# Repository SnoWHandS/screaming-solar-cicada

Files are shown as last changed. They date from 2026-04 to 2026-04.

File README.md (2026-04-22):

# Screaming Solar Cicada

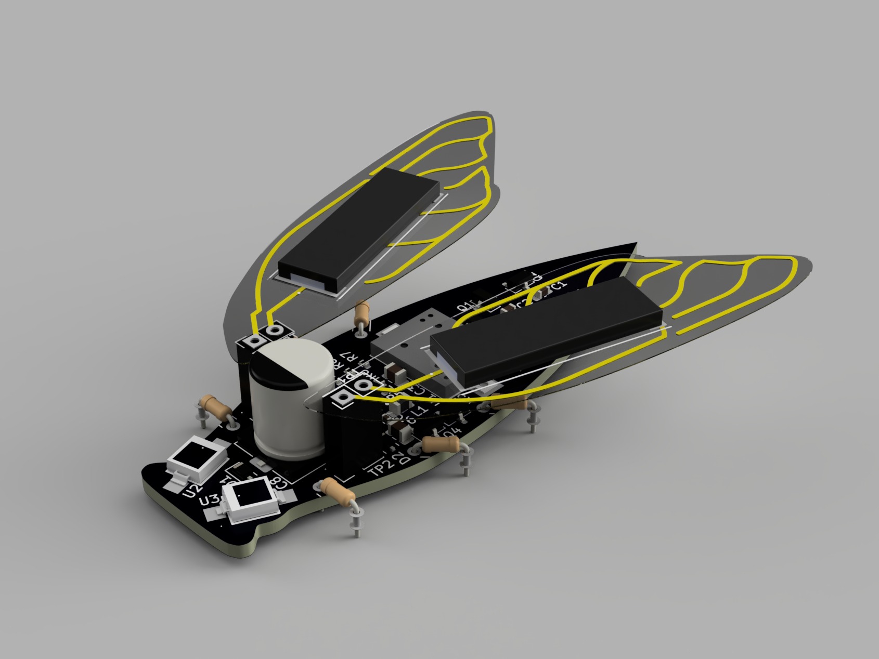
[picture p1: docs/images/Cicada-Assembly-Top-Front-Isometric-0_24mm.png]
Top Front Isometric View

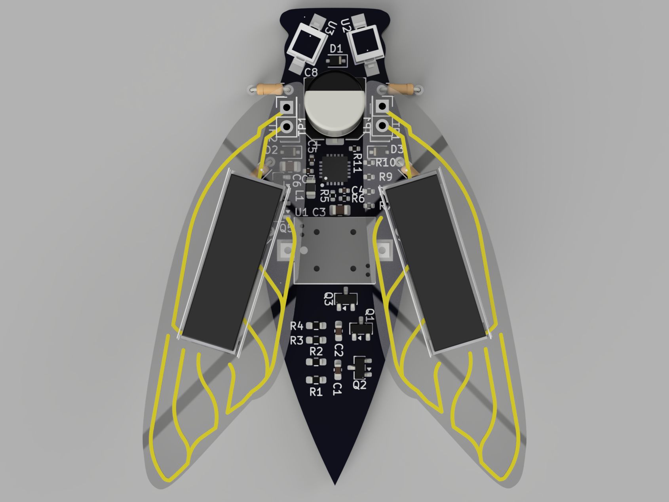
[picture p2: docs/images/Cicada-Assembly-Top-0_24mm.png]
Top View


A sun-fed, MCU-free noise bug that trickle-charges from a tiny **Anysolar KXOB** “SolarBIT” module, then screams in bursts when the storage node crosses a “battery good” threshold—then goes quiet until the cap refills. No code, no sleep states—just **PV → boost → cap → hysteresis → load switch → discrete astable → magnetic buzzer.**

---

## How it works (signal chain)

### 1. Harvest (KXOB)

The main energy source is a compact monocrystalline **KXOB** module—for example **KXOB25-04X3F** / **-TR** class (~22 × 7 mm, ~2 V MPP neighborhood, ~10–15 mA-scale current under decent light).

- The panel feeds `VIN_DC` through a **BAT54-class Schottky** (polarity, forward drop, and saner behavior when the charger isn’t drawing).
- **Stringing:** This design targets **1S** (one module) so `VIN_DC` stays inside the **BQ25505** window. **2S** only if you prove worst-case open-circuit never violates `VIN_DC` limits (**~5.1 V** recommended, **5.5 V** abs max). **Parallel** modules are fine for more charging current in weak light.

### 2. PMIC

**TI BQ25505** — **22 µH** boost from `VIN_DC` ↔ `LBOOST`; cold-start from **~600 mV** typical at the input (after the diode, plan margin), then normal operation down to very low `VIN` once running.

**MPPT** uses a high-impedance divider on `VOC_SAMP` from `VIN_DC` so the chip tracks a fraction of the panel’s open-circuit voltage (KXOB **V<sub>OC</sub>** is usually **~2–3 V** class depending on SKU and illumination).

### 3. Storage and thresholds

Energy stacks on the storage / `VSTOR`–`VBAT_*` network. The main reservoir is a large electrolytic (**1000 µF / 6.3 V** on the tank in `crktboi`).

| Function | Programming |
|---|---|
| **`VBAT_OV`** | Two-resistor divider from `VRDIV` — build uses **~6.8 MΩ + 6.2 MΩ** (~**13 MΩ** total class). |
| **`VBAT_OK`** | Three-resistor string (**~5.1 MΩ + 5.11 MΩ + 5.11 MΩ** class) — rising vs falling “turn load on/off” vs **`VBIAS` ≈ 1.21 V**. |

Sanity-check **`VBAT_OV` ≥ `VBAT_OK` rising threshold** per TI ordering rules; divider pin mapping matters.

### 4. Load switch

`VBAT_OK` drives **2N7002** → **AO3401A** high-side: **`Vstore` → `+3V0`** to the audio section. When the tank sags past the low trip, `+3V0` collapses and the chirp ends.

### 5. Noise

**BC847** astable — **~174 kΩ** + **1 nF** timing (**~4 kHz** ballpark), **~1 kΩ** collectors. **GSC1102YB-3V4000** buzzer does the actual scream.

#### Oscillator Design

The discrete astable multivibrator is built around a pair of BC847 NPN transistors. The selected RC timing values (`174 kΩ` and `1 nF`) tune the oscillation frequency to approximately 4 kHz, which closely matches the resonant frequency of the magnetic buzzer to produce the loudest possible chirp.

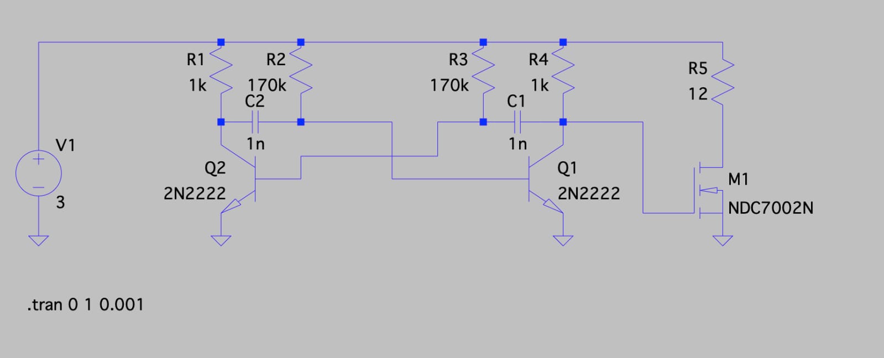
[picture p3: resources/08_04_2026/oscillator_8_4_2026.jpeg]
Astable Multivibrator Schematic


*Schematic of the oscillator circuit.*

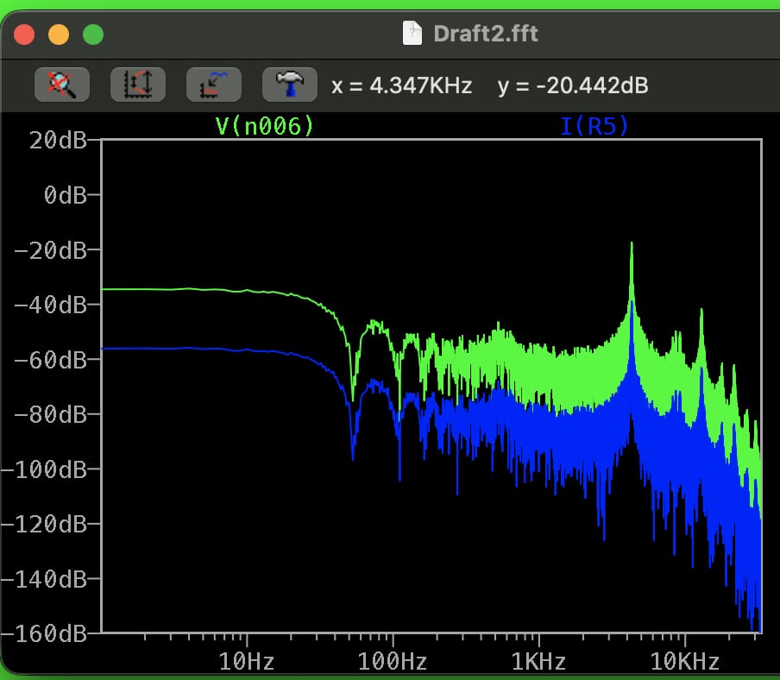
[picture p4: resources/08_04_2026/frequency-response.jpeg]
Oscillator Frequency Response


*Frequency response showing the ~4 kHz operating point.*

---

## Early direction (not the hero)

The first concept used **arrays of VBPW34S photodiodes** (**3S×3P** strings, per-string Schottkys, picky light economics). That stays interesting as a stunt, but this description treats it as **initial exploration** — the **KXOB** is the practical, repeatable harvester you’d actually leave on a windowsill.

---

## Repo / CAD

**KiCad** project **`crktboi`**:

- **`power`** sheet — KXOB / `VIN_DC`, BQ25505, load switch  
- **`oscillator`** sheet — astable + buzzer  

**ERC** and **Highlight net** are the real documentation.

---

## Expectations

- **Chirp cadence** — charge rate from the KXOB in your real light vs load current when the PFET is on — scale like **Δ*t* ~ *C*·Δ*V* / *I*<sub>load</sub>**.
- **Louder / longer** — more µF or lower mean buzzer current.
- **More frequent chirps** — more mW from the cell or a tighter OK window (trade noise against TI threshold constraints).

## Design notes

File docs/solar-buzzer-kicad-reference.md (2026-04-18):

# Solar buzzer — KiCad implementation reference

Reference diagrams and wiring notes for the solar-diode–powered buzzer: photodiode array, BQ25505, load switch, and astable oscillator. Example values reference `jmny-crkt` and **`crktboi/power.kicad_sch`** as implemented.

**Same-sheet net labels:** In KiCad, **local (or global) labels** connect nets without drawing every wire across the sheet. **ERC**, **Tools → Update PCB from Schematic**, and **right-click → Highlight net** are authoritative. Simple geometric “tracers” that only follow wires and ignore label names will falsely show pins as unconnected.

**VSTOR vs VRDIV (TI datasheet):** Pin **19 (VSTOR)** is the boost output—“typically connected to the **system load**”—with **CSTOR** (e.g. 4.7 µF + 0.1 µF) to VSS. You do **not** tie the tops of the **VBAT_OV** / **VBAT_OK** resistor strings to VSTOR. Those strings are biased from pin **8 (VRDIV)** (“connect high side of resistor divider networks to this biasing voltage”). **OK_HYST** / **OK_PROG** are midpoints of dividers **between VRDIV and GND**. **VOC_SAMP** (MPPT) is a midpoint of a divider **between VIN_DC and GND** (or other connections per datasheet), not from VRDIV. The chip pulses VRDIV during sampling so divider current is not continuous.

**Wrong advice (do not follow):** “Connect VSTOR to the L1 / input-side tank node; relabel nets.” **Ignore that.** VSTOR is **not** on the inductor or VIN path. The only place `L1` belongs is **between VIN_DC (pin 2) and LBOOST (pin 20)**. The “tank” / bulk storage lives on **VBAT_PRI / VBAT_SEC / mux** per your topology—not wired to the switching node.

---

## 1. Overall block diagram

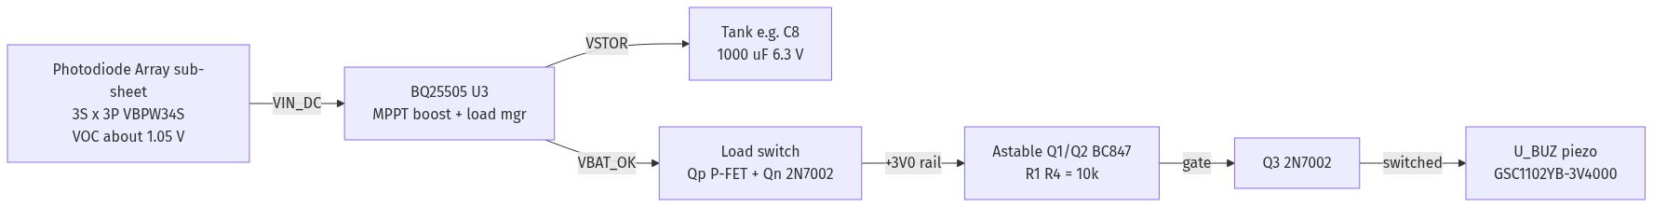
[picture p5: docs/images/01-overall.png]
Overall system block: PV → BQ25505 → tank → load switch → astable → buzzer


*Source: [`images/01-overall.mmd`](images/01-overall.mmd) — regenerate PNG via [Kroki](https://kroki.io) or `@mermaid-js/mermaid-cli`.*

---

## 2. Photodiode array (new sub-sheet `photodiode_array.kicad_sch`)

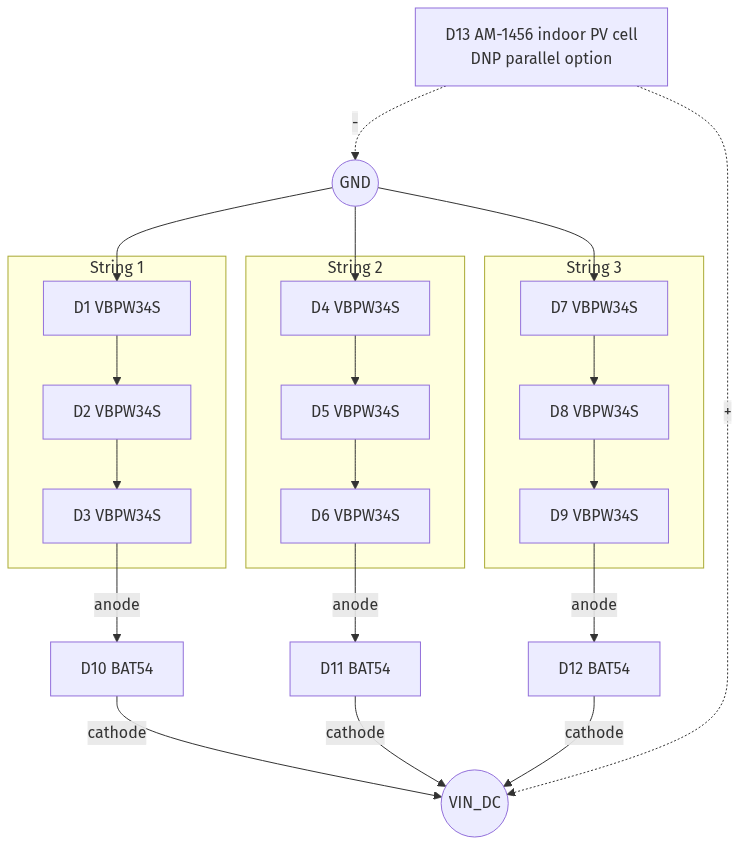
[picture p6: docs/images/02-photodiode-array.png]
3S×3P VBPW34S strings with BAT54 OR-ing and optional DNP indoor cell


*Source: [`images/02-photodiode-array.mmd`](images/02-photodiode-array.mmd).*

**Notes**

- Each string: three VBPW34S in series, positive end through a BAT54 Schottky to `VIN_DC`, negative end to GND.
- Optional DNP footprint for `AM-1456` or `KXOB25-05X3F-TR` in parallel for later experiments.
- Export `VIN_DC` and `GND` as hierarchical labels to the top sheet.

---

## 3. BQ25505 (U3) — pin wiring

| Pin | Name (datasheet) | Connect to | Notes |
|-----|---|---|---|
| 1 | VSS | GND | Analog ground (remove stray `~EN` label if present) |
| 2 | VIN_DC | `VIN_DC` + `C_IN` 4.7 µF to GND + one side of `L1` | Input from solar array |
| 3 | VOC_SAMP | Midpoint of MPPT divider **between VIN_DC and GND** (`R3`/`R4` or as in datasheet) | Not fed from VRDIV |
| 4 | VREF_SAMP | `C2` 10 nF to GND | MPPT hold cap |
| 5 | ~EN | GND | Enables IC (active low) |
| 6 | NC | Open | — |
| 7 | VBAT_OV | Midpoint of `R1` / `R2` between **VRDIV** and GND | OV programming (datasheet Eq. 2) |
| 8 | VRDIV | **IC output:** top of `R1` and top of `R5` (high side of OV + OK ladders to GND) | Do not confuse with VSTOR |
| 9 | ~VB_SEC_ON | NC (or test point) | Output only |
| 10 | ~VB_PRI_ON | NC (or test point) | Output only |
| 11 | OK_HYST | `R5` / `R6` midpoint | Upper hysteresis tap |
| 12 | OK_PROG | `R6` / `R7` midpoint | Lower (drop-out) tap |
| 13 | VBAT_OK | `Qn` gate via `R_gate_n` 100 kΩ | Drives load switch |
| 14 | VBAT_PRI | `VCAP` net → bulk tank (e.g. **1000 µF 6.3 V** `C8` in crktboi) | Primary storage |
| 15 | VSS | GND | Power ground |
| 16 | NC | Open | — |
| 17 | NC | Open | — |
| 18 | VBAT_SEC | Secondary storage / same energy node as your tank (often commoned with VSTOR for one cap) | Datasheet: ≥100 µF equivalent if used as SEC |
| 19 | VSTOR | Boost output: **CSTOR** to GND, then **system path** (internal mux / external PFETs to rail, or your load switch) | **Not** the top of ROV/ROK dividers—that is **VRDIV** |
| 20 | LBOOST | Other side of `L1` | Boost switch node |
| 21 | E_PAD | GND | Exposed thermal pad |

### Power sheet schematic (target topology)

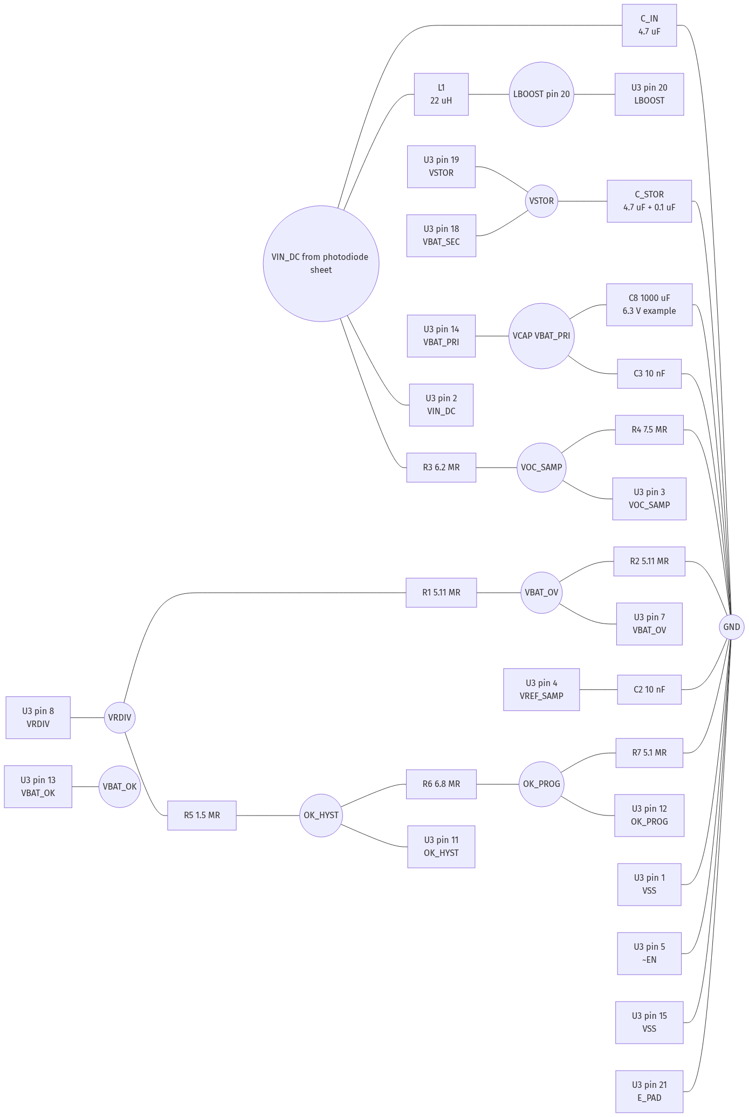
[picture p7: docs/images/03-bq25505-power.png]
BQ25505 target topology: boost, VSTOR, VCAP tank, VRDIV-fed dividers, MPPT from VIN_DC


*Source: [`images/03-bq25505-power.mmd`](images/03-bq25505-power.mmd). Resistor designators in the figure are illustrative; match your sheet.*

### `crktboi` — pre-order verification (not a “todo” list)

Use this **after** your schematic is wired; it does **not** repeat steps you have already completed. If **ERC is clean** and nets match the datasheet, you are done with topology.

1. **Labels:** Confirm critical nets (`Vstore`, `VCAP`, `V_RDIV`, `VBAT_OK`, `+3V0`, `GND`, `VIN_DC`, `LBOOST`, etc.) with **Highlight net** — especially where you used **labels instead of long wires**.
2. **BQ25505 rules of thumb (TI):** `L1` only **VIN_DC ↔ LBOOST**; **VSTOR** is boost output + CSTOR + output path (not the top of OV/OK dividers — that is **VRDIV**); **MPPT** tap **VOC_SAMP** from a divider on **VIN_DC** / GND (not from VRDIV). If your sheet already follows that, no change needed.
3. **Tank:** You added **1000 µF 6.3 V** (`C8`); adjust only if chirp length / cadence needs tuning.
4. **Load switch (Q4 / Q5):** Topology is **N-FET** inverts **VBAT_OK**, **P-FET** high-side to **`+3V0`**. Double-check symbols vs footprint: **P-FET source → `Vstore`**, **drain → `+3V0`**; **N-FET source → GND**, **drain → P-FET gate**. Add **1 MΩ** `Vstore` → P-FET gate if you want a defined off-state (optional **100 kΩ** on **VBAT_OK → Q4 gate**, **100 nF** on **`+3V0`**).
5. **ERC / DRC:** Run schematic **ERC** and board **DRC** before fab; fix any **floating pin** or **power pin** warnings on **U4**.

---

## 4. Load switch (VSTOR to +3V0)

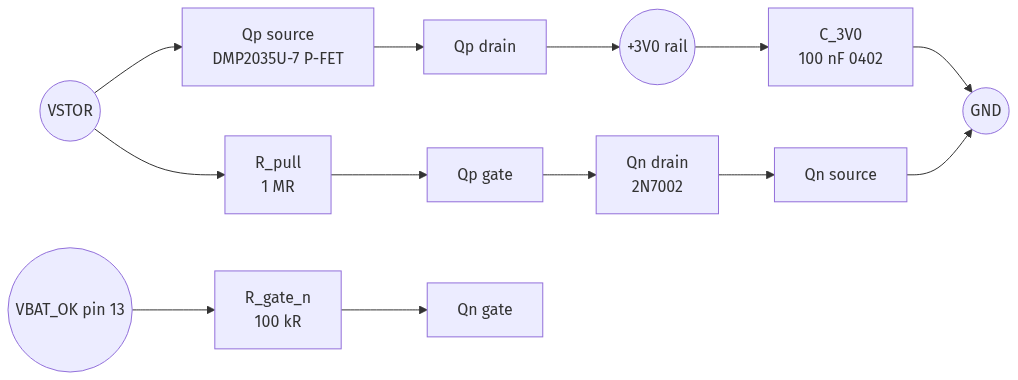
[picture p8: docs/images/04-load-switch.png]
High-side P-FET + N-FET inverter from VBAT_OK with pull-up and decoupling


*Source: [`images/04-load-switch.mmd`](images/04-load-switch.mmd).*

**Behavior**

- `VBAT_OK` low → Qn off → Qp gate pulled to VSTOR via `R_pull` → `Vgs,Qp = 0` → Qp off → `+3V0` disconnected.
- `VBAT_OK` high → Qn on → Qp gate to GND → `Vgs,Qp ≈ -3 V` → Qp on → `+3V0 ≈ VSTOR`.
- Hysteresis is set by BQ25505 OK_HYST / OK_PROG.

---

## 5. Oscillator + buzzer (`oscillator.kicad_sch`)

Use a **standard** astable: collectors pull up to `+3V0` through `R1`/`R4`, emitters to GND. If the schematic had collectors on GND and emitters on the timing nets, flip it.

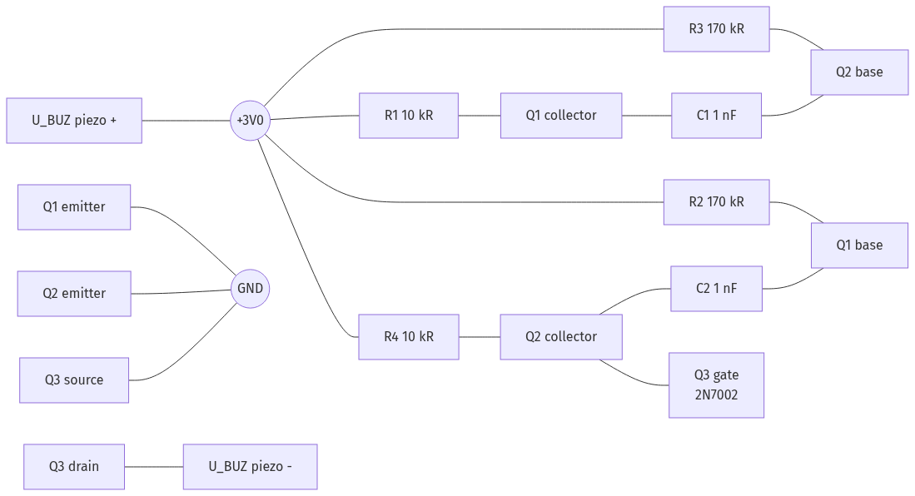
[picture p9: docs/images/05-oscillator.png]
Astable BC847 multivibrator and 2N7002 piezo driver


*Source: [`images/05-oscillator.mmd`](images/05-oscillator.mmd).*

**BC847 pinout (KiCad):** 1 = B, 2 = E, 3 = C.

**Edits**

- `Q1` / `Q2`: C through `R1` / `R4` to `+3V0`; E to GND; B to base resistor + cross cap.
- `Q3`: G on `Q2` collector; S on GND; D on piezo `-`. Piezo `+` on `+3V0`.
- Change oscillator `R1` and `R4`: **1 kΩ → 10 kΩ**.
- Keep `R2`, `R3`, `C1`, `C2` as in the resonance plan (~4 kHz for GSC1102YB).

---

## 6. Thresholds and cadence (existing power resistors)

With `V_BIAS = 1.21 V` (BQ25505 typical):

| Quantity | Formula | Value |
|---|---|---|
| `VBAT_OV` | `1.5 × 1.21 × (1 + R1/R2)` with R1=R2=5.11 MΩ | **3.63 V** |
| `VBAT_OK_HYST` (load ON) | `1.21 × (1 + (R5+R6)/R7)` | **3.18 V** |
| `VBAT_OK_PROG` (load OFF) | `1.21 × (1 + R6/R7)` | **2.82 V** |
| MPPT ratio | `R4/(R3+R4)` | **≈ 55 %** (TEG-style; OK for photodiodes indoors) |

**1000 µF tank (between ~3.18 V and ~2.82 V)** — same as **1 mF**

- `E ≈ 0.5 × 1000 µF × (3.18² − 2.82²) ≈ 1.08 mJ`
- At ~1.5 mW chirp load: **~720 ms** tone
- At ~7 µW average harvest (500 lux ballpark): recharge **~155 s** (~2.5 min between chirps)

**Alternatives**

- **470 µF:** shorter chirp, faster cadence.
- **2.2 mF:** longer chirp, slower cadence.

---

## 7. Parts delta summary

**Add**

- 9× VBPW34S
- 3× BAT54 (string isolation)
- 1× AM-1456 or KXOB25-05X3F-TR footprint (DNP optional)
- 1× **1000 µF 6.3 V** on `VCAP` (e.g. `C8` / `JVJ6.3V1000M8X10` in crktboi), or 470–680 µF if you want shorter chirps
- 1× DMP2035U-7 (or AO3401) P-FET — Qp
- 1× 2N7002 — Qn (BOM can match Q3)
- 1× 1 MΩ 0402 — R_pull
- 1× 100 kΩ 0402 — R_gate_n
- 1× 100 nF 0402 — C_3V0 on `+3V0` after switch
- 1× 4.7 µF — C_IN, VIN_DC to GND
- 1× 10 µF — C_STOR, VSTOR to GND (if not already present as C1)

**Change**

- Oscillator `R1`, `R4`: 1 kΩ → **10 kΩ**

**Remove / DNP**

- Extra legacy 4700 µF footprints if you removed them in favor of one bulk cap
- Orphan `Vstore`-only caps if not on a real net

---

*Generated as a working reference for KiCad entry. Update values after bench verification.*

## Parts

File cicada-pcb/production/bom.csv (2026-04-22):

Designator | Footprint | Quantity | Value | LCSC Part #
C1, C2 | 0603 | 2 | 1nF | C100040
C3, C6 | 0805 | 2 | 10uF | C307520
C4, C5, C7 | 0402 | 3 | 10nF | C327025
C8 | CP_Elec_8x10 | 1 | 1000uF, 6.3V | C49256842
D1, D2, D3 | D_SOD-323F | 3 | BAT54J | C130415
L1 | 0805 | 1 | 22uH | C383411
Q1, Q2 | SOT-23 | 2 | BC847 | C2138
Q3, Q4 | SOT-23 | 2 | 2N7002 | C8545
Q5 | SOT-23 | 1 | AO3401A | C15127
R1, R4 | 0603 | 2 | 1kR | C22548
R10 | 0402 | 1 | 6.8 MR | C477775
R11 | 0402 | 1 | 5.1 MR | C477747
R12, R13, R14, R15, R16, R17 | R_Axial_DIN0204_L3.6mm_D1.6mm_P5.08mm_Horizontal | 6 | R
R2, R3 | 0603 | 2 | 170kR | C22890
R5, R6 | 0402 | 2 | 5.11 MR | C477744
R7 | 0402 | 1 | 6.2 MR | C477768
R8 | 0402 | 1 | 7.5 MR | C327241
R9 | 0402 | 1 | 1.5 MR | C138034
TP1, TP2 | PinSocket_2x01_P2.54mm_Vertical | 2 | TestPoint_2Pole | C492401
U1 | BUZ-SMD_L11.0-W9.0 | 1 | GSC1102YB-3V4000 | C255332
U2, U3 | SENSOR-SMD_L4.4-W3.9 | 2 | VBPW34S | C145262
U4 | QFN50P350X350X100-21N-D | 1 | BQ25505RGRT | C2876730

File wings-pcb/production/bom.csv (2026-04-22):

Designator | Footprint | Quantity | Value | LCSC Part #
B1, B2 | KXOB25_AAR | 2 | KXOB25-03X4F-TB
TP1 | PinSocket_2x01_P2.54mm_Vertical | 1 | TestPoint_2Pole | C492401

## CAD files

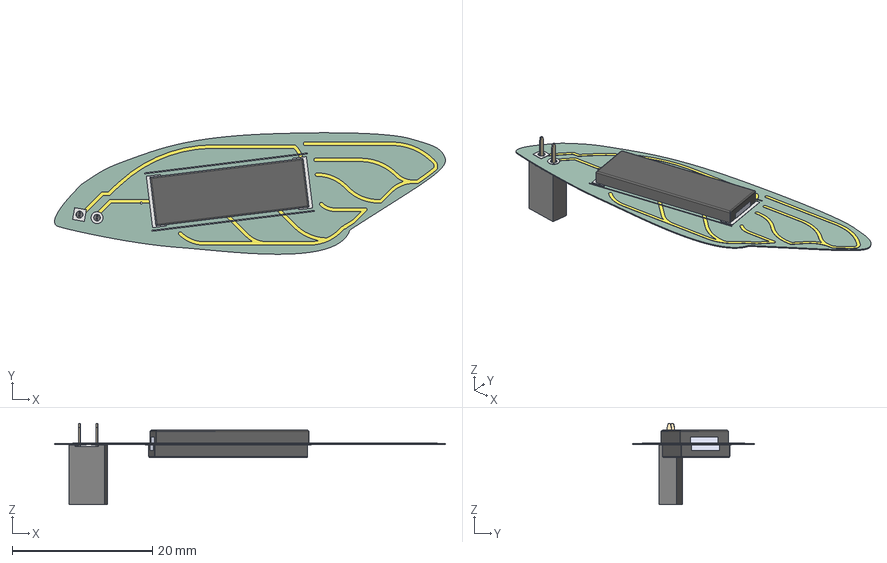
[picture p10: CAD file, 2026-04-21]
wings-pcb/3D/wings-dbl-sided-0_24mmThick.step
55.8 x 17.3 x 11.6 mm
PinSocket_2x01_P2.54mm_Vertical
wings_copper
wings_pad
wings_via
wings_silkscreen x 2
wings_PCB

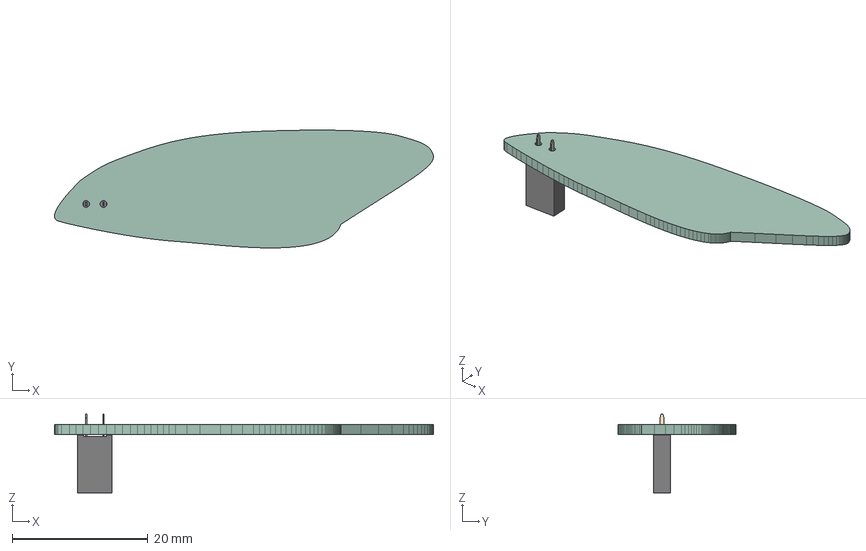
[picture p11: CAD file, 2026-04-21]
wings-pcb/wing.step
55.8 x 17.3 x 11.6 mm
PinSocket_2x01_P2.54mm_Vertical
wings_PCB

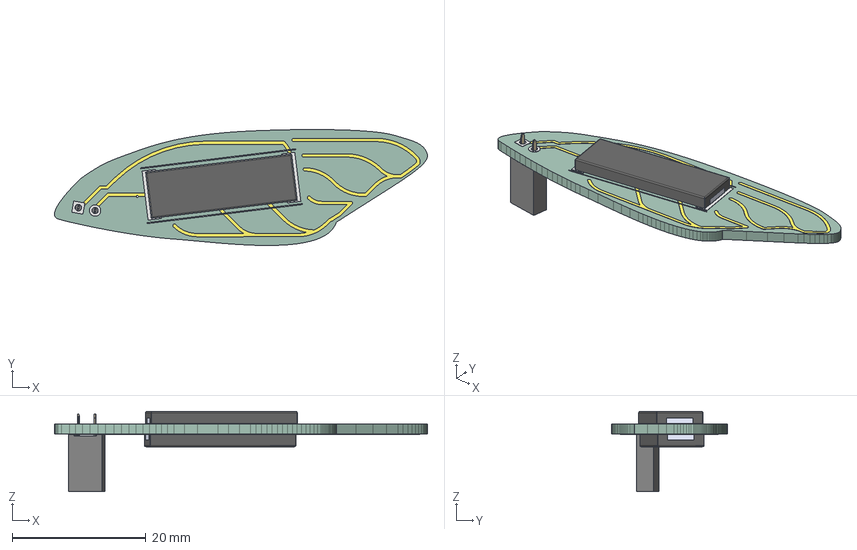
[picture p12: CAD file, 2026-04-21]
wings-pcb/3D/wings-dbl-sided.step
55.8 x 17.3 x 12.0 mm
PinSocket_2x01_P2.54mm_Vertical
wings_copper
wings_pad
wings_via
wings_silkscreen x 2
wings_PCB

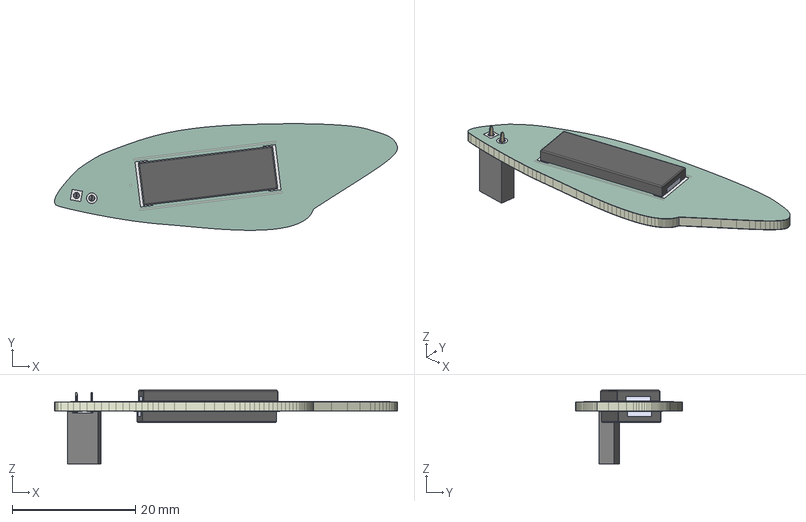
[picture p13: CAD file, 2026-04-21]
wings-pcb/3D/wings.step
55.8 x 17.3 x 12.0 mm
PinSocket_2x01_P2.54mm_Vertical
wings_copper
wings_pad
wings_via
wings_silkscreen x 2
wings_soldermask x 2
wings_PCB

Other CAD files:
wings-pcb/wing.stl

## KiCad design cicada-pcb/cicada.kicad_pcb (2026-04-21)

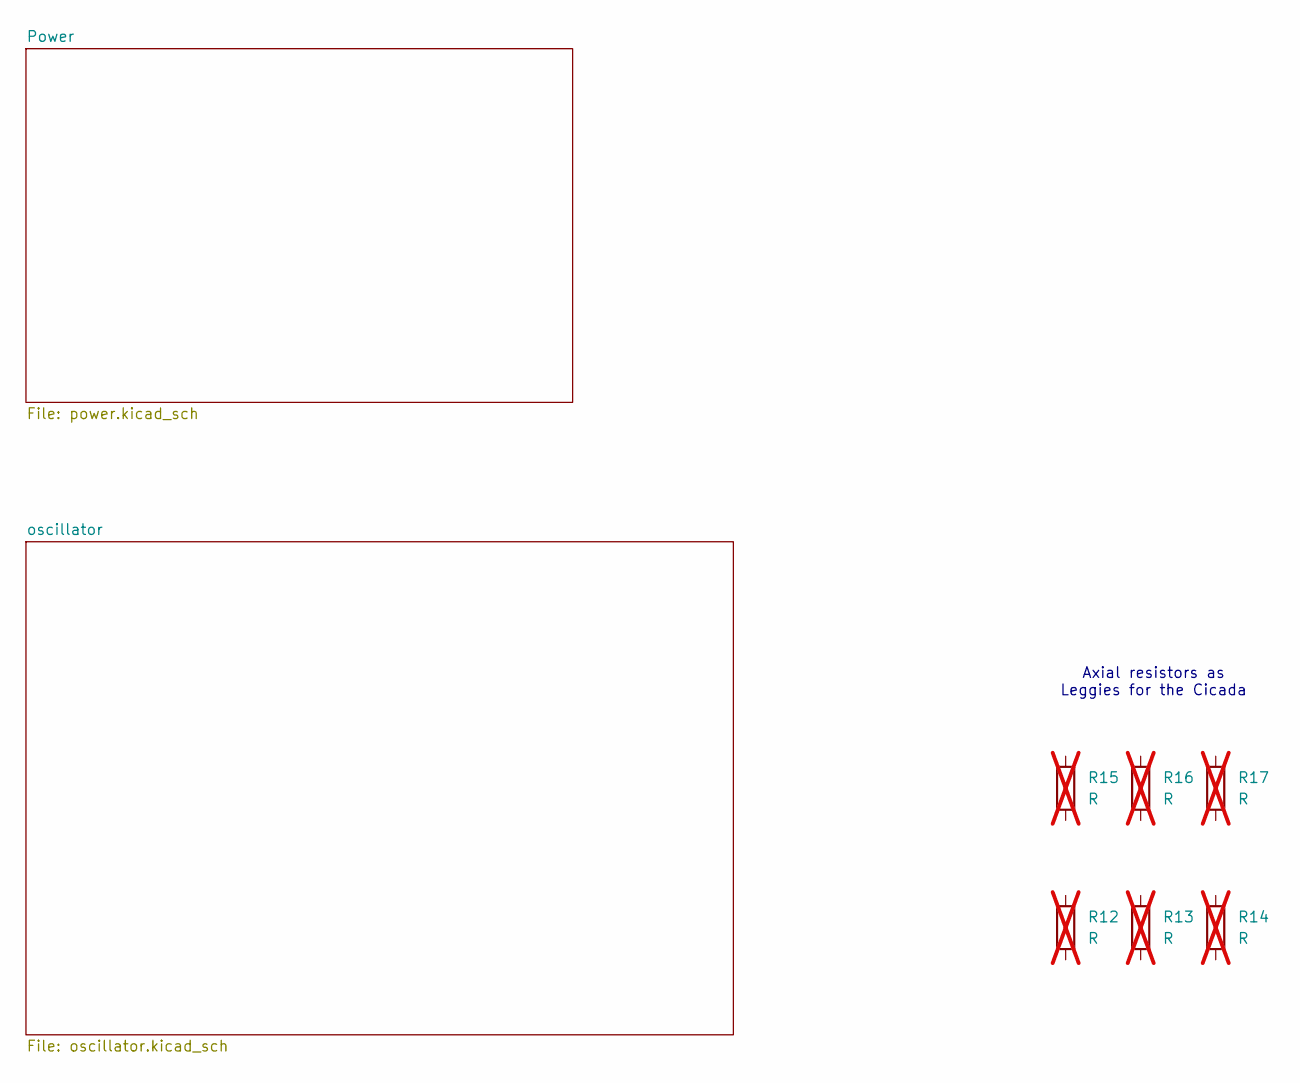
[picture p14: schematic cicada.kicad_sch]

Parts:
R12, R13, R14, R15, R16, R17: R; R_Axial_DIN0204_L3.6mm_D1.6mm_P5.08mm_Horizontal; not fitted

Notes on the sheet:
Axial resistors as Leggies for the Cicada

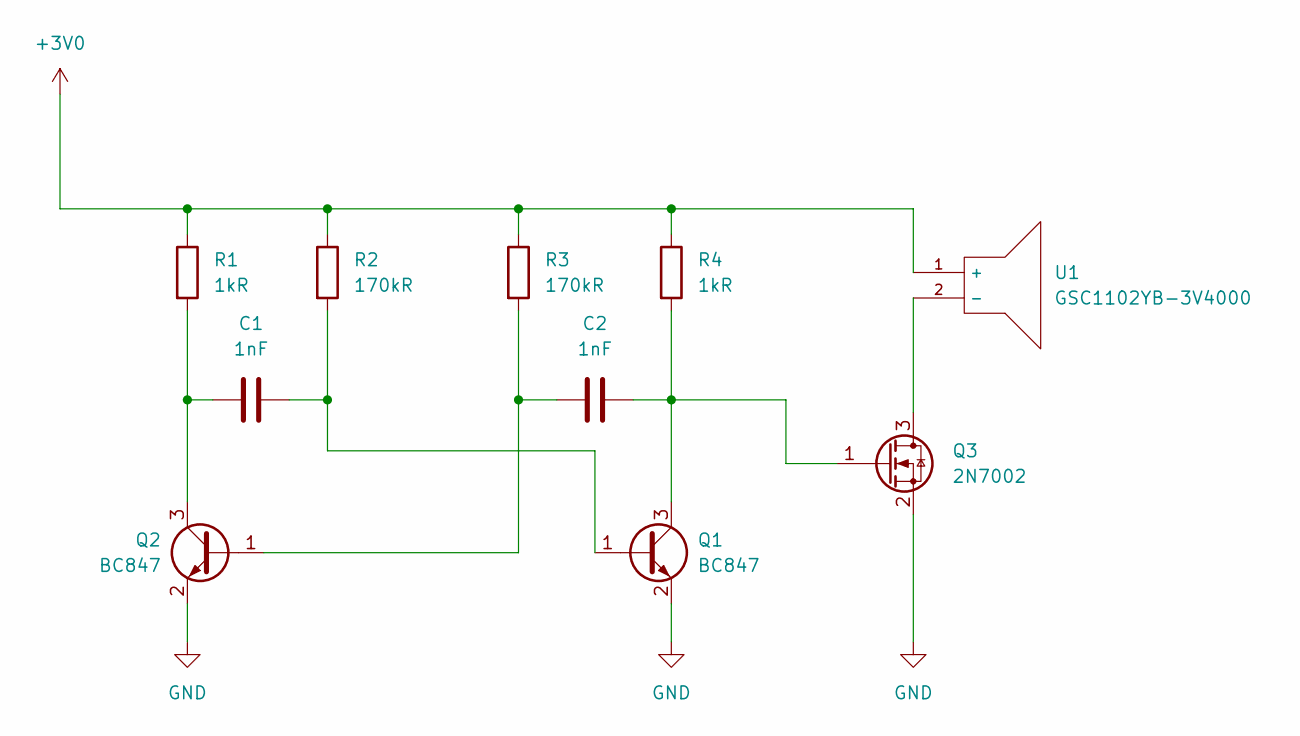
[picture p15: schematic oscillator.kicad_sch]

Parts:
C1, C2: 1nF; C_0603_1608Metric_Pad1.08x0.95mm_HandSolder; LCSC C100040
Q1, Q2: BC847; SOT-23; LCSC C2138
Q3: 2N7002; SOT-23; LCSC C8545
R1, R4: 1kR; R_0603_1608Metric_Pad0.98x0.95mm_HandSolder; LCSC C22548
R2, R3: 170kR; R_0603_1608Metric_Pad0.98x0.95mm_HandSolder; LCSC C22890
U1: GSC1102YB-3V4000; BUZ-SMD_L11.0-W9.0; LCSC C255332

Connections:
+3V0: R1.1, R2.1, R3.1, R4.1, U1.1 (+); also elsewhere on the board
GND: Q1.2 (E), Q2.2 (E), Q3.2 (S); also elsewhere on the board
unnamed: C1.2, Q1.1 (B), R2.2
unnamed: C2.2, Q1.3 (C), Q3.1 (G), R4.2
unnamed: C2.1, Q2.1 (B), R3.2
unnamed: C1.1, Q2.3 (C), R1.2
unnamed: Q3.3 (D), U1.2 (-)

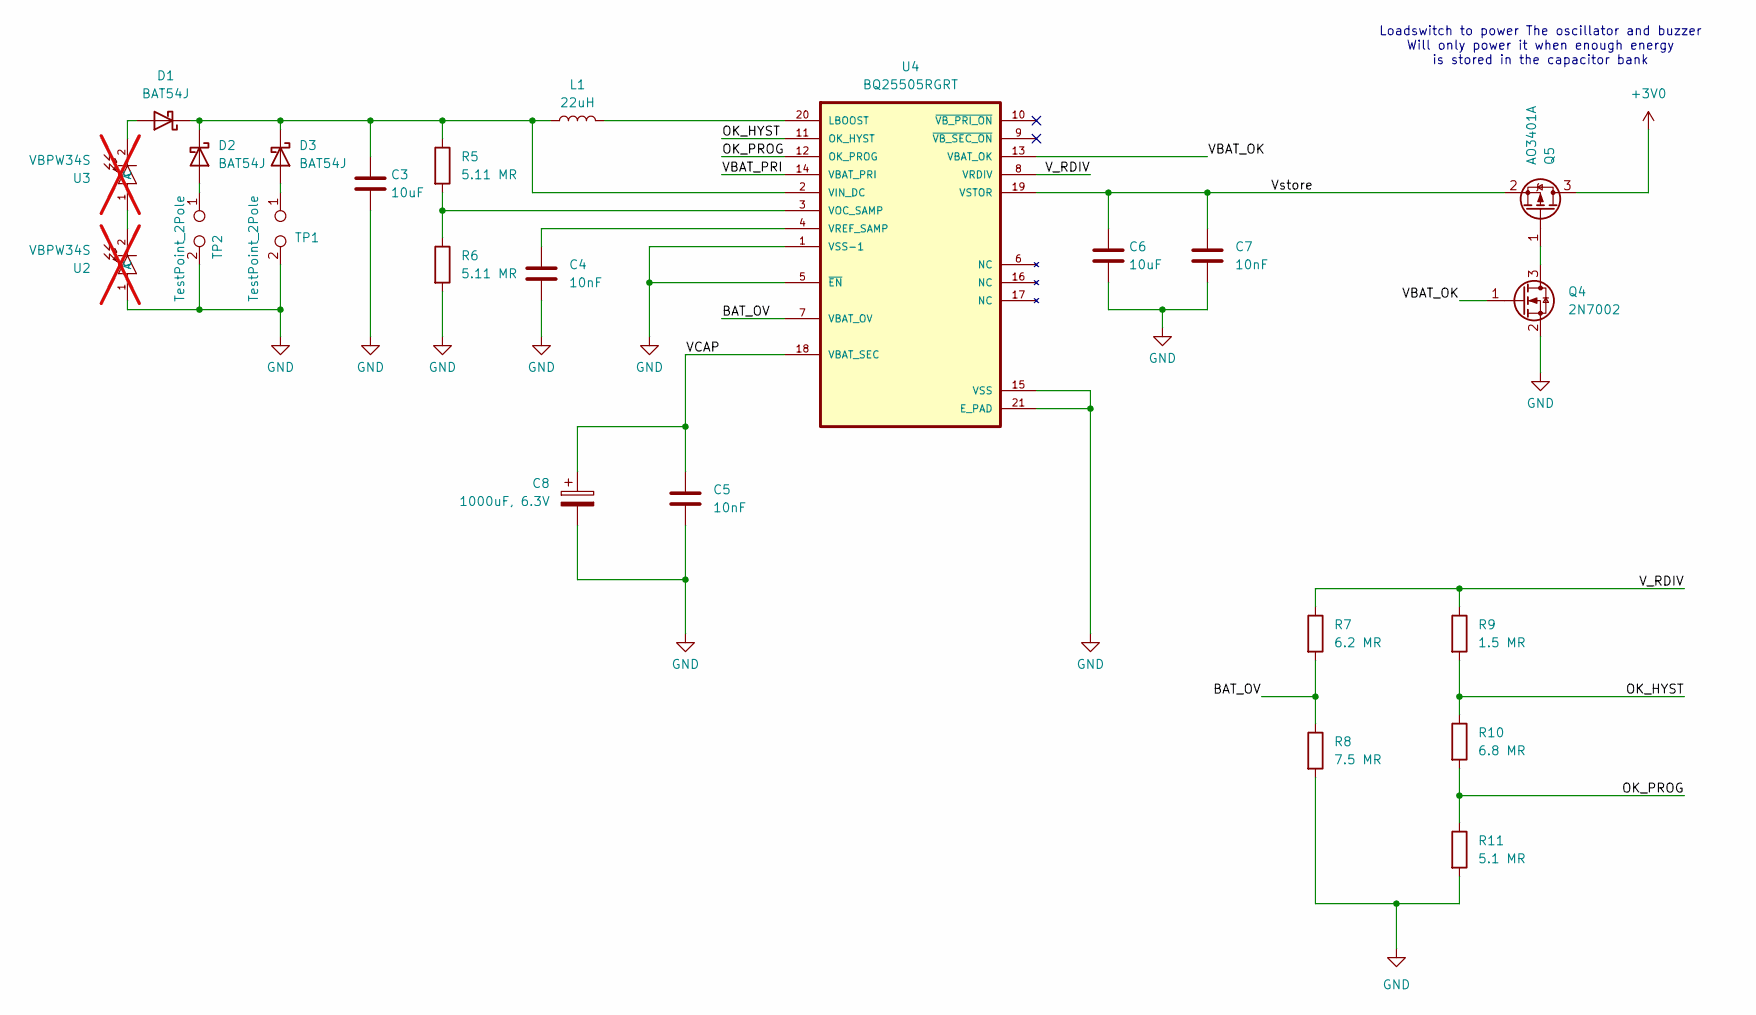
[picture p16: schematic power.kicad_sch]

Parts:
C3, C6: 10uF; C_0805_2012Metric; PARTNO CL21A106KOQNNNG; LCSC C307520
C4, C5, C7: 10nF; C_0402_1005Metric; PARTNO CC0402KRX7R8BB103; LCSC C327025
C8: 1000uF, 6.3V; CP_Elec_8x10; LCSC C49256842
D1, D2, D3: BAT54J; D_SOD-323F; LCSC C130415
L1: 22uH; L_0805_2012Metric; PARTNO MLZ2012N220LT000; LCSC C383411
Q4: 2N7002; SOT-23; LCSC C8545
Q5: AO3401A; SOT-23; LCSC C15127
R5, R6: 5.11 MR; R_0402_1005Metric; PARTNO RC0402FR-075M11L; LCSC C477744
R7: 6.2 MR; R_0402_1005Metric; PARTNO RM04J625CT; LCSC C477768
R8: 7.5 MR; R_0402_1005Metric; PARTNO RC0402FR-077M5L; LCSC C327241
R9: 1.5 MR; R_0402_1005Metric; PARTNO RK73H1ETTP1504F; LCSC C138034
R10: 6.8 MR; R_0402_1005Metric; PARTNO CRCW04026M80FKED; LCSC C477775
R11: 5.1 MR; R_0402_1005Metric; PARTNO RK73H1ETTP5104F; LCSC C477747
TP1, TP2: TestPoint_2Pole; PinSocket_2x01_P2.54mm_Vertical; LCSC C492401
U2, U3: VBPW34S; SENSOR-SMD_L4.4-W3.9; LCSC C145262; not fitted
U4: BQ25505RGRT; QFN50P350X350X100-21N-D; PARTNO BQ25505RGRT; LCSC C2876730

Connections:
+3V0: Q5.3 (D); also elsewhere on the board
/Power/BAT_OV: R7.2, R8.1, U4.7 (VBAT_OV)
/Power/OK_HYST: R9.2, R10.1, U4.11 (OK_HYST)
/Power/OK_PROG: R10.2, R11.1, U4.12 (OK_PROG)
/Power/VBAT_OK: Q4.1 (G), U4.13 (VBAT_OK)
/Power/VBAT_PRI: U4.14 (VBAT_PRI)
/Power/VCAP: C5.1, C8.1, U4.18 (VBAT_SEC)
/Power/V_RDIV: R7.1, R9.1, U4.8 (VRDIV)
/Power/Vstore: C6.1, C7.1, Q5.2 (S), U4.19 (VSTOR)
GND: C3.2, C4.2, C5.2, C6.2, C7.2, C8.2, Q4.2 (S), R6.2, R8.2, R11.2, TP1.2, TP2.2, U2.1 (A), U4.1 (VSS-1), U4.5 (~EN), U4.15 (VSS), U4.21 (E_PAD); also elsewhere on the board
unnamed: D1.2 (A), U3.2 (C)
unnamed: C3.1, D1.1 (K), D2.1 (K), D3.1 (K), L1.1, R5.1, U4.2 (VIN_DC)
unnamed: D2.2 (A), TP2.1
unnamed: D3.2 (A), TP1.1
unnamed: Q4.3 (D), Q5.1 (G)
unnamed: U2.2 (C), U3.1 (A)
unnamed: L1.2, U4.20 (LBOOST)
unnamed: R5.2, R6.1, U4.3 (VOC_SAMP)
unnamed: C4.1, U4.4 (VREF_SAMP)

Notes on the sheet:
Loadswitch to power The oscillator and buzzer Will only power it when enough energy is stored in the capacitor bank

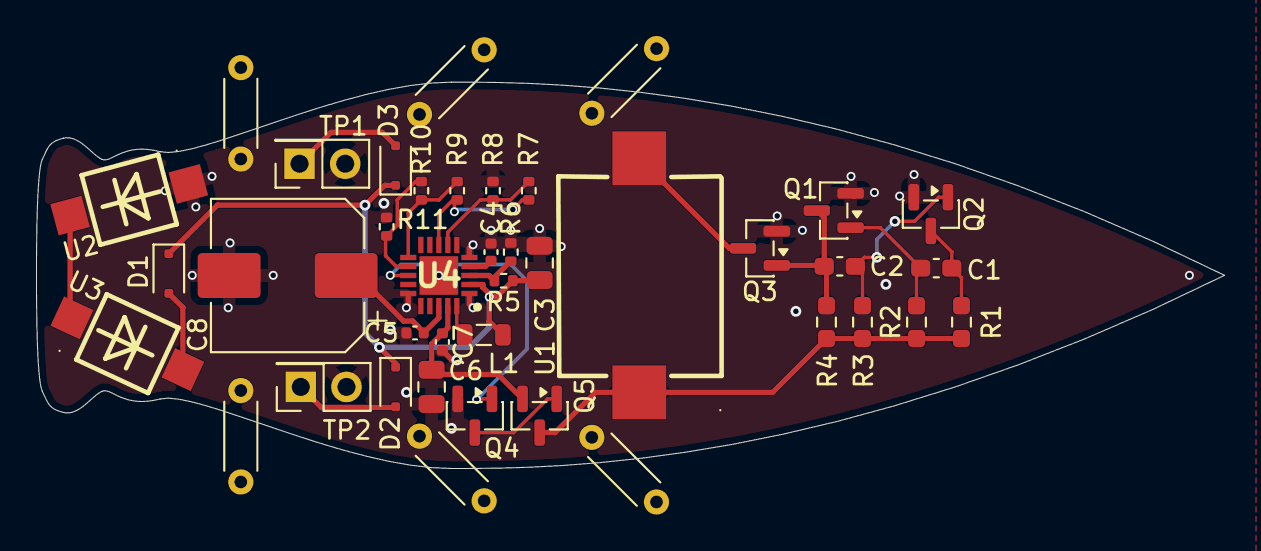
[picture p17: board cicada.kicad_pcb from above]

Board: 2 copper layers, 66.0 x 21.5 mm, 40 parts (0 on the bottom side), 23 nets.

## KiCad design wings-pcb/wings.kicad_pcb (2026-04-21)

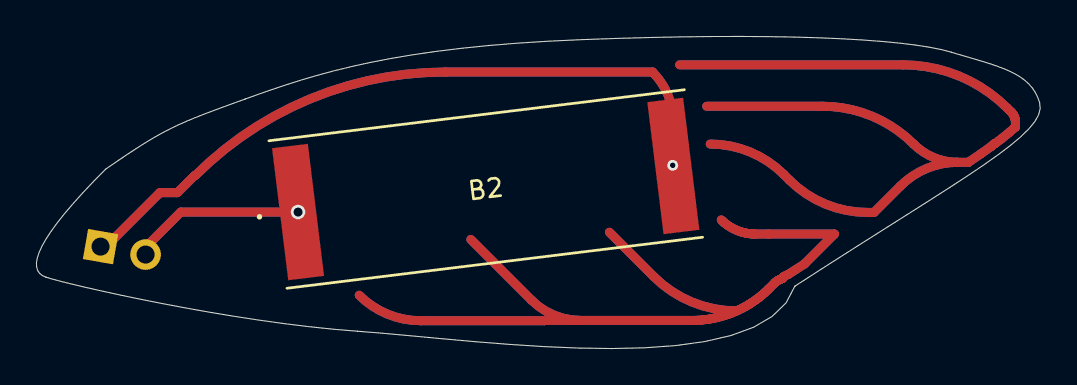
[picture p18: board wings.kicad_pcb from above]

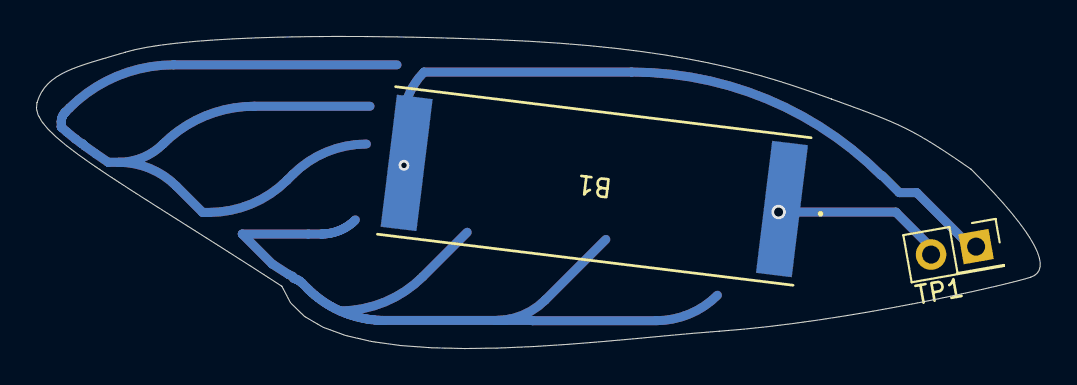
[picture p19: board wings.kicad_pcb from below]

Board: 2 copper layers, 55.8 x 17.3 mm, 3 parts (2 on the bottom side), 2 nets.

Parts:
B1, B2: KXOB25-03X4F-TB; KXOB25_AAR
TP1: TestPoint_2Pole; PinSocket_2x01_P2.54mm_Vertical

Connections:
unnamed: B1.1, B2.1, TP1.2
unnamed: B1.2, B2.2, TP1.1

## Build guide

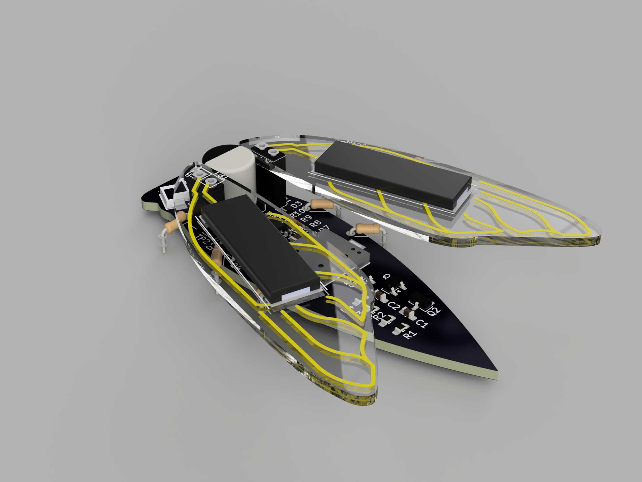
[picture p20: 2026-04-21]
docs/images/Cicada-Assembly-top-isometric.png

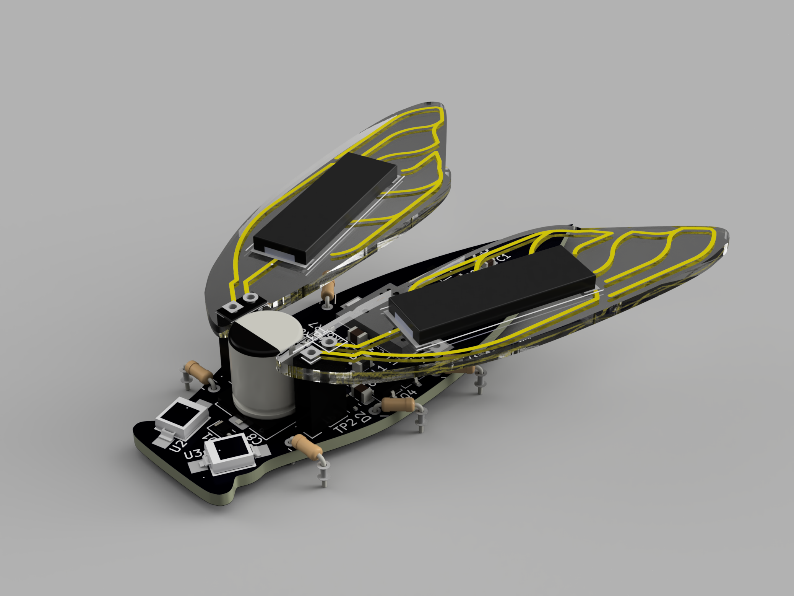
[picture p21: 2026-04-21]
docs/images/Cicada-Assembly-Top-Front-Isometric.png

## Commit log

2026-04-11 oscill schem
    [oscillator_1.kicad_sch]
2026-04-11 fix things
    [oscillator.kicad_sch, oscillator_1.kicad_sch]
2026-04-11 new proj that might work
    [crktboi.kicad_pcb, crktboi.kicad_sch]
2026-04-11 lil pcb
    [crktboi.kicad_pcb, crktboi.kicad_sch, oscillator.kicad_sch]
2026-04-11 Made some progress on the BQ25505 in the old schematic. Will polish it off and import into new project next.
    [oscillator.kicad_sch, power.kicad_sch]
2026-04-16 Added the power circuit to the design and considered VBAT_OK as the power control output for the design. Still todo is reducing capacitor bank size and adjusting BQ25505 parameters
    [crktboi.kicad_sch, oscillator.kicad_sch, power.kicad_sch]
2026-04-18 Added a plan document & updated design with tweaks for 3S3P photodiodes
    [crktboi.kicad_pcb, crktboi.kicad_sch, oscillator.kicad_sch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]
2026-04-18 Updated PCB layout with all parts I think we need for power.
    [crktboi.kicad_pcb]
2026-04-18 Added LCSC part numbers to each part in the schematic
    [oscillator.kicad_sch, power.kicad_sch]
2026-04-19 Changed the shape to be a bit more like a cicada. Added 3D models to parts missing their assignment
    [crktboi.kicad_pcb]
2026-04-19 Added photodiodes to the base design for eyes on the cicada.
    [crktboi.kicad_pcb, power.kicad_sch]
2026-04-19 Added resistors as legs for the cicada and updated LCSC part numbers for new parts
    [crktboi.kicad_pcb, crktboi.kicad_sch, power.kicad_sch]
2026-04-19 Completed the board layout and ran through the DRC. Adjusted clearance limits to make it work
    [crktboi.kicad_pcb]
2026-04-19 Created fabrication files and added back csv files from the gitignore
    [bom.csv, designators.csv, positions.csv]
2026-04-19 Created a wing project and tried to get the outline of a wing. Having issues with board outline overlap when importing outlines from pictures online
    [crktboi.kicad_pcb, wings.kicad_pcb, wings.kicad_sch]
2026-04-20 big panel, new wing
    [wings.kicad_pcb, wings.kicad_sch]
2026-04-21 Added BAT54J diodes to the input connectors of the PV headers
    [crktboi.kicad_pcb, power.kicad_sch]
2026-04-21 Added a graphic to the back of the base board of a Cicada
    [crktboi.kicad_pcb]
2026-04-21 removed the cicada graphic a it was too busy
    [crktboi.kicad_pcb]
2026-04-21 tracks for wings
    [wings.kicad_pcb, wings.kicad_sch]
2026-04-21 rotated terminals
    [wings.kicad_pcb]
2026-04-21 Created 3D models of main body board, wings and double sided wings. added 3D models for solar cells
    [wings-dbl-sided.step, wings.kicad_pcb, wings.step]
2026-04-21 Created gerbers of Wing and 3D renders of the assembly for docs
    [bom.csv, designators.csv, positions.csv]
2026-04-21 Updated Gerbers of new body PCB
    [bom.csv, crktboi.kicad_pcb, designators.csv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]
2026-04-21 Changed wings to 0.24mm thick FPC and re-rendered
    [wings-dbl-sided-0_24mmThick.step, wings.kicad_pcb]
2026-04-22 Renamed everything from jmny cricket to cicada
    [bom.csv, cicada.kicad_pcb, cicada.kicad_sch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]
